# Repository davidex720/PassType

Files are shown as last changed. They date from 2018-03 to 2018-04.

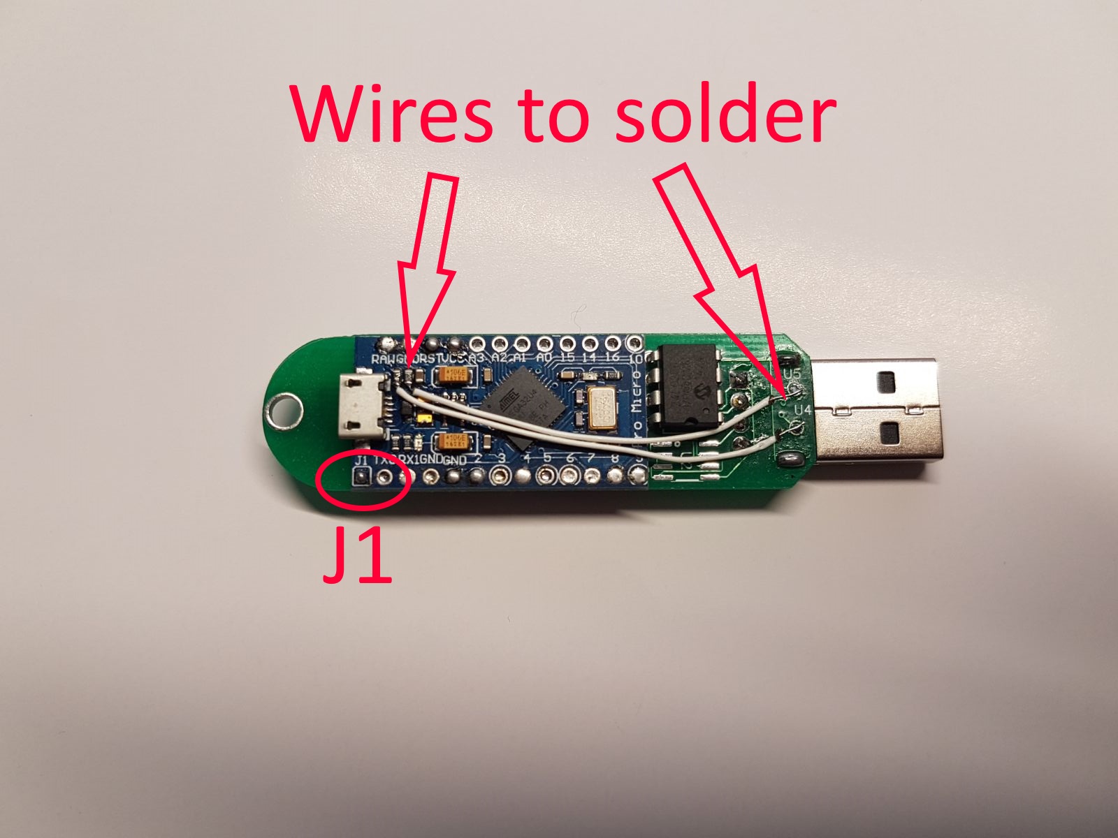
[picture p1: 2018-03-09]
PassType Shield/v1/Guide/backSide_PassTypeShield.jpg

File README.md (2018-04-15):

# PassType

#### A COMMERCIAL, UPGRADED AND "READY TO USE" VERSION IS COMING SOON!! READ MORE [HERE](https://github.com/davidex720/PassType/tree/master/PassType%20Pro)

PassType is small and versatile USB HID device: name something you can do with keyboard and mouse on your computer and PassType can do it for you faster, better and a million times over!

## The idea

Quite often you are requested to log in to accounts from a pc that is not yours, from a device you don't fully trust or to do repetitive tasks. You can use the always same password but it is a very bad practice with awfull consequences... you should use 10 characters or more passwords with numbers, symbols, upper and lower case letters in it and possibly change them once in a while. A nightmare to remember and even worse to type in right at first try. Sometimes one of my relatives have problems remembering a password, such as wifi or similar stuff. PassType (yeah... this name comes from the contraction of "password type in device") is a very cheap and simple to use automation device, capable of storing password and macros and to type/execute them in every device! It works with every computer and it can even be plugged and used on smartphones. Every system supporting some sort of keyboard and/or mouse is compatible with PassType!

## A versatile set of tools for newbies and pros

This small device can be used to perform tasks that are boring, repetitive or to type in hundreds of characters in few seconds. Actually it can do everything that a human in 15 minutes can do with mouse and keyboard in only few seconds. The first version of PassType is now called PassType Shield. The name comes from the fact that it is almost a shield for Arduino Pro Micro.
__The new version will be even more flexible, have a better storing system, encryption of datas and a lot of new features in a even smaller form factor!__

## Getting Started

You can build your own PassType from scratch, buy the pcb, the already smd soldered pcb or the full device from us directly.
Contact us at davidex720@gmail.com for pcbs and full devices. All files needed are in this repo (still to be updated)

__WEBSITE COMING SOON!__

## Authors

* **Davide Nesi** - *Dev*
* **Eero Prittinen** - *Dev*

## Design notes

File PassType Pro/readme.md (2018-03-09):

# COMING SOON!

## Feauters:

  - More power
  - Cool Design
  - Integrated safety measures to securely store passwords
  - Smaller size
  - Expandable memory
  - New learning tools
  - More compatibility
  - Professional tool easy to customize
  - Open to developer

www.passtype.it

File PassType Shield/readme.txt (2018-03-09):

PassType Shield is a prototype and it was first released as a project here:
http://www.instructables.com/id/Password-Manager-Typer-Macro-Payload-All-in-ONE/

It is a dirty and cheap prototype and still in evolution, 
it is a parallel work with the coming soon improved and boosted commercial version.

Go to www.passtype.it for more information about PassType

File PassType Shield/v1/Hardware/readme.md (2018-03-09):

# Parts list for PassType Shield V1
Links here are only for reference, feel free to buy parts from the cheapest alternative in your country.
This list is made for GLOBAL shipping

#### 1. PassType Shield PCB  
   - 5$ sending an email to davidex720@gmail.com 
   - the funds rised with PassType Shield pcb will be used for the development of the upgraded, safer, commercial, "ready to use" version of this project
   - Soon on www.passtype.it

#### 2. Arduino Pro Micro 5V
   - [Source 1](https://www.aliexpress.com/item/Free-Shipping-New-Pro-Micro-for-arduino-ATmega32U4-5V-16MHz-Module-with-2-row-pin-header/2021979132.html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,searchweb201602_1_10152_10151_10065_10344_10068_10342_10325_10343_10546_10340_10548_10341_10084_10083_10618_10304_10307_5711211_10313_10059_10184_10534_100031_10103_10627_10626_10624_10623_10622_5722411_10621_10620_5711311,searchweb201603_25,ppcSwitch_3&algo_expid=4f3b485b-808f-46f2-a339-12398b33a269-0&algo_pvid=4f3b485b-808f-46f2-a339-12398b33a269&priceBeautifyAB=0)
   - [Source 2](https://www.aliexpress.com/item/1pcs-TENSTAR-ROBOT-With-the-bootloader-Black-Pro-Micro-ATmega32U4-for-arduino-5V-16MHz-Module-controller/32849563958.html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,searchweb201602_1_10152_10151_10065_10344_10068_10342_10325_10343_10546_10340_10548_10341_10084_10083_10618_10304_10307_5711211_10313_10059_10184_10534_100031_10103_10627_10626_10624_10623_10622_5722411_10621_10620_5711311,searchweb201603_25,ppcSwitch_3&algo_expid=4f3b485b-808f-46f2-a339-12398b33a269-2&algo_pvid=4f3b485b-808f-46f2-a339-12398b33a269&priceBeautifyAB=0)

#### 3. LED (128x32) (you can choose letter color: blue or white usually)
   - [Source 1](https://it.aliexpress.com/item/1pcs-0-91-inch-OLED-module-0-91-white-OLED-128X32-OLED-LCD-LED-Display-Module/32672327708.html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,searchweb201602_1_10152_10151_10065_10344_10068_10342_10325_10343_10546_10340_10548_10341_10084_10083_10618_10304_10307_5711211_10313_10059_10184_10534_100031_10103_10627_10626_10624_10623_10622_5722411_10621_10620_5711311,searchweb201603_25,ppcSwitch_3&algo_expid=b9f97773-6c42-4b48-bd19-fa79ab7d9f12-1&algo_pvid=b9f97773-6c42-4b48-bd19-fa79ab7d9f12&priceBeautifyAB=0)
   - [Source 2](https://www.aliexpress.com/item/A3-1pcs-SAMIORE-ROBOT-0-91-inch-OLED-module-0-91-white-OLED-128X32-OLED-LCD/32672229793.html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,searchweb201602_1_10152_10151_10065_10344_10068_10342_10325_10343_10546_10340_10548_10341_10084_10083_10618_10304_10307_5711211_10313_10059_10184_10534_100031_10103_10627_10626_10624_10623_10622_5722411_10621_10620_5711311,searchweb201603_25,ppcSwitch_3&algo_expid=35dfc6a5-9fdb-4644-8a68-d7f9d38b9d17-1&algo_pvid=35dfc6a5-9fdb-4644-8a68-d7f9d38b9d17&priceBeautifyAB=0)

#### 4. 5-way tactile switch
   - [Source 1](https://www.aliexpress.com/item/5-Channel-Way-Tactile-Switch-Breakout-Module-Converter-Adapter-Board-for-Arduino/32669811425.html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,searchweb201602_1_10152_10151_10065_10344_10068_10342_10325_10343_10546_10340_10548_10341_10084_10083_10618_10304_10307_5711211_10313_10059_10184_10534_100031_10103_10627_10626_10624_10623_10622_5722411_10621_10620_5711311,searchweb201603_25,ppcSwitch_3&algo_expid=3273e035-9a04-4fd0-adfe-733925e676be-0&algo_pvid=3273e035-9a04-4fd0-adfe-733925e676be&priceBeautifyAB=0)  (to desolder) 
   - [Source 2](https://www.aliexpress.com/item/free-shipping-10-pcs-7mm-x-7mm-6-Pin-5-Way-Momentary-Pushbutton-PCB-SMD-SMT/32416530444.html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,searchweb201602_1_10152_10151_10065_10344_10068_10342_10325_10343_10546_10340_10548_10341_10084_10083_10618_10304_10307_5711211_10313_10059_10184_10534_100031_10103_10627_10626_10624_10623_10622_5722411_10621_10620_5711311,searchweb201603_25,ppcSwitch_3&algo_expid=3273e035-9a04-4fd0-adfe-733925e676be-2&algo_pvid=3273e035-9a04-4fd0-adfe-733925e676be&priceBeautifyAB=0)

#### 5. EEPROM 24lc256
   - Best solution is to ask for free samples and free shipping [here](http://www.microchip.com/wwwproducts/en/24lc256)
   - Or you can buy it [here](https://www.digikey.com/product-detail/en/microchip-technology/24LC256T-I-SM/24LC256T-I-SMCT-ND/5013518)

#### 6. USB male connector
   - [Source 1](https://www.aliexpress.com/item/50Pcs-lot-USB-2-0-Male-A-Type-USB-PCB-Connector-Plug-180-degree-SMT-SMD/32707919597.html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,searchweb201602_1_10152_10151_10065_10344_10068_10342_10325_10343_10546_10340_10548_10341_10084_10083_10618_10304_10307_5711211_10313_10059_10184_10534_100031_10103_10627_10626_10624_10623_10622_5722411_10621_10620_5711311,searchweb201603_25,ppcSwitch_3&algo_expid=a10d68d0-b656-4def-88e3-eda41a465fa2-3&algo_pvid=a10d68d0-b656-4def-88e3-eda41a465fa2&priceBeautifyAB=0)
   - [Source 2](https://www.aliexpress.com/item/82Pcs-14-Styles-USB-Male-USB-Female-Mini-USB-SMD-Vertical-Socket-Connector-for-DIY-Jack/32821827485.html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,searchweb201602_1_10152_10151_10065_10344_10068_10342_10325_10343_10546_10340_10548_10341_10084_10083_10618_10304_10307_5711211_10313_10059_10184_10534_100031_10103_10627_10626_10624_10623_10622_5722411_10621_10620_5711311,searchweb201603_25,ppcSwitch_3&algo_expid=a10d68d0-b656-4def-88e3-eda41a465fa2-8&algo_pvid=a10d68d0-b656-4def-88e3-eda41a465fa2&priceBeautifyAB=0)

## YOU DO NOT NEED SPARE RESISTORS FOR THIS VERSION OF PASSTYPE SHIELD!!!

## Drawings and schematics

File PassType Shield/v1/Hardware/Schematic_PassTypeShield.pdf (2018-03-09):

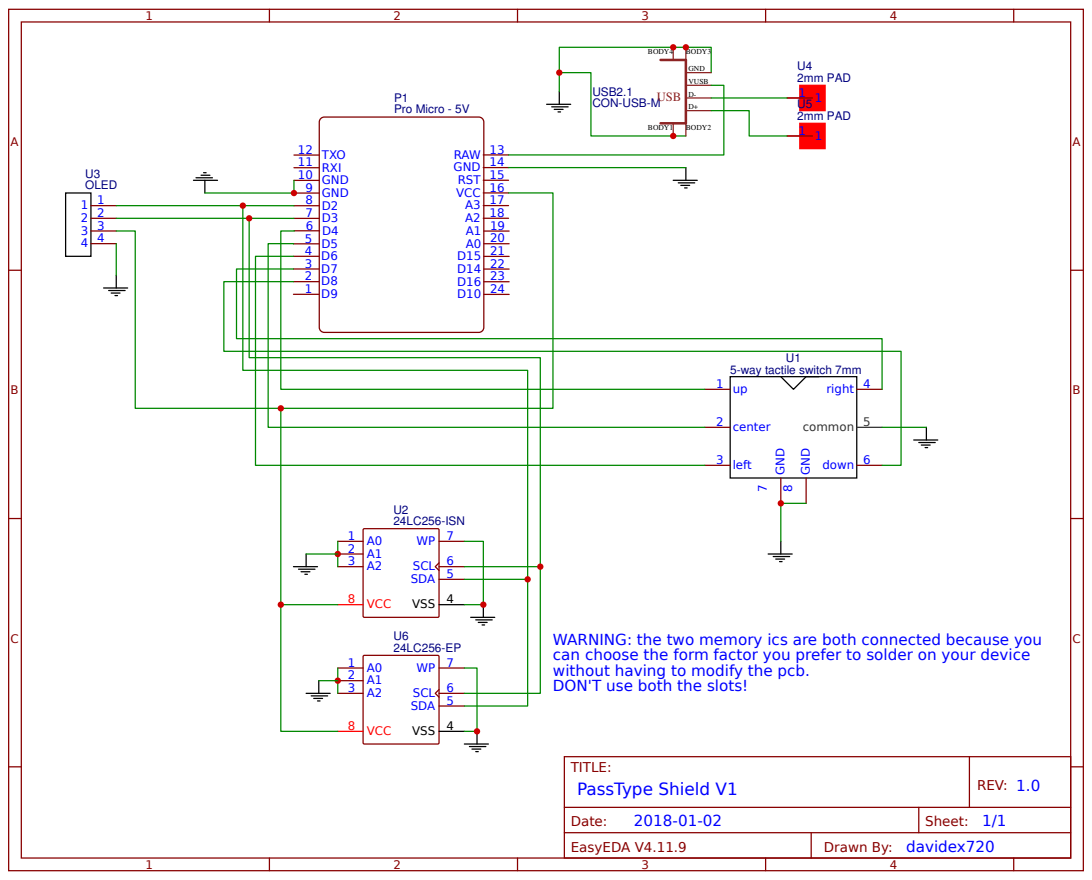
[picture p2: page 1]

WARNING: the two memory ics are both connected because you
can choose the form factor you prefer to solder on your device
without having to modify the pcb.
DON'T use both the slots!

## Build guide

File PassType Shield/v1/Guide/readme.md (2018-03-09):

#Step by step guide building DIY PassType Shield

1. Solder the 24LC256 to the PassType Shield pcb. Choose only one of the two sockets (smd or arduino pin compatible package)

2. Solder the USB male connector if you have a PassType Shield pcb without it already soldered on it

3. Solder the OLED module in position and trim away the pins

4. Solder the Arduino Pro Micro as flush as you can with the pcb using pins and trim them
  4.1 If you have an Arduino Pro Micro with J1 open solder the jumper close (see image) 

5. Solder two small wires as in the picture, they will provide data output to the USB connector integrated on PassType Shield 
**BE SUPER CAREFUL ABOUT THE SOLDERING ON ARDUINO PRO MICRO! IF YOU HEAT TOO MUCH THE BOARD OR MAKE THE WRONG SOLDERING YOU CAN DAMAG YOUR ARDUINO!**

6. Solder the 5-way switch (the mini joystick)

7. Plug the Arduino Pro Micro micro usb port on your computer and check you can programm it. Now feel free to develop your software
   use the one you find in this github repo! 

8. Enjoy!

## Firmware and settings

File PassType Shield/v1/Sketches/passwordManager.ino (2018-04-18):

//TODO add more settings
//TODO login/unlock
//TODO psw names with upper and lower case
//TODO accept only showrt password names
//TODO optimize memory
//TODO graphic revision for arrows
//TODO long press = multiple press
//TODO add more chars
//TODO standby function
//TODO get a better randPSW
//TODO RESET SYSTEM AFTER 3 WRONG LOGIN ATTEMPTS
//TODO add scrolling text for long names





#include <U8g2lib.h>
#include <Wire.h>
#include "Keyboard.h"


//DISPLAY CONSTRUCTOR
U8G2_SSD1306_128X32_UNIVISION_F_HW_I2C u8g2(U8G2_R0, SCL, SDA, U8X8_PIN_NONE);
//U8G2_SSD1306_128X32_UNIVISION_F_HW_I2C u8g2(U8G2_R2, SCL, SDA, U8X8_PIN_NONE);



//EEPROM VALUE
#define disk1 0x50
#define byteResetValue 255
#define endAddressZone 255
#define dimPSW 40
#define startPSWzone 5000
#define endPSWzone 15200
#define settingStartAddress 32500

//Settings
#define firstUse 32501              //255 first use
#define pswLength 32502             //5,6,7,8,9,10,11,12,13,14,15,16  ---------default 10 value 255
#define pswType  32503              //1 only lowercase, 2 lower+upper case, 3 letters+numbers, 4 letters+numbers+symbols -------255 default letters+numbers

//JOYSTICK
#define upPin  4
#define centerPin  5
#define leftPin  6
#define rightPin  7
#define downPin  8

//setting per UI
#define longPressedTime 40
#define longPressQuant  7


#define spacing 12   //spacing
#define pswLength 10

int buttonState;
int lastButtonState = 0;
int cyclePressed = 0;



//BITMAPS
const u8g2_uint_t leftArrow[]  = {
  0x00,          // 00000000
  0x20,          // 00100000
  0x60,          // 01100000
  0xE0,          // 11100000
  0xE0,          // 11100000
  0x60,          // 01100000
  0x20,          // 00100000
  0x00,          // 00000000
};
const u8g2_uint_t rigthArrow[]  = {
  0x00,          // 00000000
  0x80,          // 10000000
  0xC0,          // 11000000
  0xE0,          // 11100000
  0xE0,          // 11100000
  0xC0,          // 11000000
  0x80,          // 10000000
  0x00,          // 00000000
};
const u8g2_uint_t downArrow[]  = {
  0x00,          // 00000000
  //0x7E,          // 01111110
  0x3C,          // 00111100
  0x18,          // 00011000
};
const u8g2_uint_t upArrow[]  = {
  0x18,          // 00011000
  0x3C,          // 00111100
  //0x7E,          // 01111110
  0x00,          // 00000000
};

const u8g2_uint_t center[]  = {
  0x3C,          // 00111100
  0x42,          // 01000010
  0x5A,          // 01011010
  0x5A,          // 01011010
  0x42,          // 01000010
  0x3C,          // 00111100
};

const u8g2_uint_t verticalTYPE[]  = { //TODO could use only letters ad mitmaps to optimize memory
  0x70,          // 01110000
  0x20,          // 00100000
  0x20,          // 00100000
  0x20,          // 00100000
  0x20,          // 00100000
  0x00,          // 00000000

  0x50,          // 01010000
  0x50,          // 01010000
  0x20,          // 00100000
  0x20,          // 00100000
  0x20,          // 00100000
  0x00,          // 00000000

  0x70,          // 01110000
  0x50,          // 01010000
  0x70,          // 01110000
  0x40,          // 01000000
  0x40,          // 01000000
  0x00,          // 00000000

  0x70,          // 01110000
  0x40,          // 01000000
  0x70,          // 01110000
  0x40,          // 01000000
  0x70,          // 01110000
  0x00,          // 00000000

};

const u8g2_uint_t verticalEDIT[]  = {
  0x70,          // 01110000
  0x40,          // 01000000
  0x70,          // 01110000
  0x40,          // 01000000
  0x70,          // 01110000
  0x00,          // 00000000

  0x60,          // 01100000
  0x50,          // 01010000
  0x50,          // 01010000
  0x50,          // 01010000
  0x60,          // 01100000
  0x00,          // 00000000

  0x20,          // 00100000
  0x20,          // 00100000
  0x20,          // 00100000
  0x20,          // 00100000
  0x20,          // 00100000
  0x00,          // 00000000

  0x70,          // 01110000
  0x20,          // 00100000
  0x20,          // 00100000
  0x20,          // 00100000
  0x20,          // 00100000
  0x00,          // 00000000

};

const u8g2_uint_t verticalBACK[]  = {
  0x70,          // 01110000
  0x48,          // 01001000
  0x70,          // 01110000
  0x48,          // 01001000
  0x70,          // 01110000
  0x00,          // 00000000

  0x20,          // 00100000
  0x50,          // 01010000
  0x70,          // 01110000
  0x50,          // 01010000
  0x50,          // 01010000
  0x00,          // 00000000

  0x30,          // 00110000
  0x40,          // 01000000
  0x40,          // 01000000
  0x40,          // 01000000
  0x30,          // 00110000
  0x00,          // 00000000

  0x40,          // 01000000
  0x50,          // 01010000
  0x60,          // 01100000
  0x50,          // 01010000
  0x48,          // 01001000
  0x00,          // 00000000

};

const u8g2_uint_t verticalOK[]  = {
  0x20,          // 00100000
  0x50,          // 01010000
  0x50,          // 01010000
  0x50,          // 01010000
  0x20,          // 00100000
  0x00,          // 00000000

  0x40,          // 01000000
  0x50,          // 01010000
  0x60,          // 01100000
  0x50,          // 01010000
  0x48,          // 01001000
  0x00,          // 00000000

};

const uint8_t logo[] PROGMEM  = {
  0x00, 0x00, 0x00, 0x00, 0x00, 0x00, 0x00, 0x00, 0x00, 0x00, 0x00, 0x00, 0x00, 0x00, 0x00, 0x00
  , 0x00, 0x00, 0x00, 0x00, 0x00, 0x00, 0x00, 0x00, 0x00, 0x00, 0x00, 0x00, 0xfe, 0xff, 0x03, 0x00
  , 0x00, 0x00, 0x00, 0x00, 0x00, 0x00, 0x00, 0x00, 0x00, 0x00, 0x00, 0x00, 0xff, 0xff, 0x07, 0x00
  , 0x00, 0x00, 0x00, 0x00, 0x00, 0x00, 0x00, 0x00, 0x00, 0x00, 0x00, 0x80, 0x03, 0x00, 0x0e, 0x00
  , 0x00, 0x00, 0x00, 0x00, 0x00, 0x00, 0x00, 0x00, 0x00, 0x00, 0x00, 0xc0, 0x01, 0x00, 0x1c, 0x00
  , 0x00, 0x00, 0x00, 0x00, 0x00, 0x00, 0x00, 0x00, 0x00, 0x00, 0x1c, 0xe0, 0x00, 0x00, 0x38, 0x00
  , 0x00, 0x00, 0x00, 0x00, 0x00, 0x00, 0x00, 0x00, 0x00, 0x00, 0x7e, 0x70, 0x00, 0x00, 0x70, 0x00
  , 0x00, 0x00, 0x00, 0x00, 0x00, 0x00, 0x00, 0x00, 0x00, 0x00, 0xfe, 0x3f, 0x00, 0x00, 0xe0, 0x00
  , 0x00, 0x00, 0xc0, 0x07, 0x00, 0x00, 0x00, 0x03, 0x00, 0x00, 0xfe, 0x1f, 0x00, 0x00, 0xc0, 0x00
  , 0x00, 0x00, 0xe0, 0x1f, 0x00, 0x00, 0x0e, 0x03, 0x00, 0x7e, 0xfe, 0x1f, 0x00, 0x00, 0xc0, 0x00
  , 0x00, 0x00, 0x64, 0x38, 0x00, 0x83, 0x0f, 0x07, 0x00, 0xff, 0x00, 0x1c, 0x00, 0x00, 0xc0, 0x00
  , 0x00, 0x00, 0x66, 0x30, 0x80, 0xc7, 0x03, 0xbf, 0x40, 0xc3, 0x7c, 0x1c, 0x00, 0xf8, 0xc0, 0x00
  , 0x00, 0x00, 0xe7, 0x9f, 0xc1, 0x6c, 0x00, 0xbf, 0x61, 0xc3, 0xfe, 0x1c, 0x00, 0x04, 0xc1, 0x00
  , 0x00, 0x80, 0xe7, 0x8f, 0x67, 0x60, 0x00, 0x83, 0x61, 0x7f, 0xc6, 0x1c, 0x00, 0x02, 0xc2, 0x00
  , 0x00, 0xc0, 0xe3, 0x00, 0x6f, 0xc0, 0x07, 0x83, 0x63, 0x3f, 0xc6, 0x1c, 0x00, 0x02, 0xc2, 0x00
  , 0x00, 0xe0, 0xe3, 0x00, 0xcc, 0x87, 0x0f, 0x03, 0x7f, 0x03, 0xfe, 0x1c, 0x00, 0x02, 0xc2, 0x00
  , 0x00, 0xe0, 0xe3, 0x00, 0x8c, 0x0f, 0x0c, 0x03, 0x7e, 0x03, 0x7e, 0x1c, 0x00, 0x02, 0xc2, 0x00
  , 0x00, 0xe0, 0xe3, 0xc0, 0x0f, 0x0c, 0x0c, 0x03, 0x60, 0x03, 0x06, 0x1c, 0x00, 0x02, 0xc2, 0x00
  , 0x00, 0xc0, 0xe3, 0x60, 0x0c, 0x0e, 0x0f, 0x07, 0x70, 0x03, 0x06, 0x1c, 0x00, 0x04, 0xc1, 0x00
  , 0x00, 0x80, 0xe7, 0x60, 0xec, 0xe7, 0x07, 0xbe, 0x3f, 0x03, 0x7c, 0x1c, 0x00, 0xf8, 0xc0, 0x00
  , 0x00, 0x00, 0xe7, 0xc0, 0xef, 0xe3, 0x01, 0xbc, 0x1f, 0x03, 0x7c, 0x1c, 0x00, 0x00, 0xc0, 0x00
  , 0x00, 0x00, 0x06, 0x00, 0x00, 0x00, 0x00, 0x00, 0x00, 0x00, 0x00, 0x1c, 0x00, 0x00, 0xc0, 0x00
  , 0x00, 0x00, 0xfc, 0xff, 0xff, 0xff, 0xff, 0xff, 0xff, 0xff, 0xff, 0x1f, 0x00, 0x00, 0xc0, 0x00
  , 0x00, 0x00, 0xf8, 0xff, 0xff, 0xff, 0xff, 0xff, 0xff, 0xff, 0xff, 0x3f, 0x00, 0x00, 0xe0, 0x00
  , 0x00, 0x00, 0x00, 0x00, 0x00, 0x00, 0x00, 0x00, 0x00, 0x00, 0x00, 0x70, 0x00, 0x00, 0x70, 0x00
  , 0x00, 0x00, 0x00, 0x00, 0x00, 0x00, 0x00, 0x00, 0x00, 0x00, 0x00, 0xe0, 0x00, 0x00, 0x38, 0x00
  , 0x00, 0x00, 0x00, 0x00, 0x00, 0x00, 0x00, 0x00, 0x00, 0x00, 0x00, 0xc0, 0x01, 0x00, 0x1c, 0x00
  , 0x00, 0x00, 0x00, 0x00, 0x00, 0x00, 0x00, 0x00, 0x00, 0x00, 0x00, 0x80, 0x03, 0x00, 0x0e, 0x00
  , 0x00, 0x00, 0x00, 0x00, 0x00, 0x00, 0x00, 0x00, 0x00, 0x00, 0x00, 0x00, 0xff, 0xff, 0x07, 0x00
  , 0x00, 0x00, 0x00, 0x00, 0x00, 0x00, 0x00, 0x00, 0x00, 0x00, 0x00, 0x00, 0xfe, 0xff, 0x03, 0x00
  , 0x00, 0x00, 0x00, 0x00, 0x00, 0x00, 0x00, 0x00, 0x00, 0x00, 0x00, 0x00, 0x00, 0x00, 0x00, 0x00
  , 0x00, 0x00, 0x00, 0x00, 0x00, 0x00, 0x00, 0x00, 0x00, 0x00, 0x00, 0x00, 0x00, 0x00, 0x00, 0x00

};




























String text = "no";
int pointedAddr = 0;
int statusMenu = 0;
String addName;
int charInName = 0;
int charIndex = 0;
int wait = 5;
int fUse = 255;


char consentiti[] = {
  ' '                                                                                                                                            //  1
  , 'a', 'b', 'c', 'd', 'e', 'f', 'g', 'h', 'i', 'j', 'k', 'l', 'm', 'n', 'o', 'p', 'q', 'r', 's', 't', 'u', 'v', 'w', 'x', 'y', 'z'             //+26
  , 'A', 'B', 'C', 'D', 'E', 'F', 'G', 'H', 'I', 'J', 'K', 'L', 'M', 'N', 'O', 'P', 'Q', 'R', 'S', 'T', 'U', 'V', 'W', 'X', 'Y', 'Z'             //+26
  , '0', '1', '2', '3', '4', '5', '6', '7', '8', '9'                                                                                             //+10 =63
  , '?', '(', ',', ')', '/', '&', '%', '$', '<', '>', '!', ']', '+', '_', '*', '.', '}', '@', '^',                                                //+19 =82
  // _     )   ,    =   -     /    %    $    ;    :    !    +    ^    ?    (    .    *    "    &


};



void setup(void) {

  pinMode(4, INPUT_PULLUP);
  pinMode(5, INPUT_PULLUP);
  pinMode(6, INPUT_PULLUP);
  pinMode(7, INPUT_PULLUP);
  pinMode(8, INPUT_PULLUP);

  u8g2.begin();
  u8g2.setFont(u8g2_font_crox4h_tr);

  Serial.begin(9600);
  Wire.begin();
  Keyboard.begin();
  randomSeed(analogRead(0));

  fUse = (int) readEEPROM(firstUse);
  if (fUse == 255) {
    //TODO first use
    //TODO set to firs use done
  } else {
    //animation
  }

}

void loop(void) {

  if (wait == 0) {
  } else if (wait == 5) {
    wait++;
  } else if (wait == 6) {
    delay(2000);
    wait = 0;
  } else {
    delay(1000);
    wait = 0;
  }

  String n;
  String v;

  if (statusMenu <= 1) {
    if (simpleAutoReadPSW(pointedAddr, &n, &v)) {
      text = n;
      statusMenu = 1;
    } else {
      text = "New PSW";
      statusMenu = 2;
    }
  }

  debounceButtons();

  //0 nothing
  //1 left
  //2 up
  //3 right
  //4 down
  //5 center
  //6 dont know

  if (statusMenu == 1) {          //------------------------------------show psw name
    if (buttonState == 0) {
      //nothing
    } else if (buttonState == 1) { //left
      //TODO typing animation
      Keyboard.print(v);
    } else if (buttonState == 2) { //up
      if (pointedAddr > 0) {
        pointedAddr--;
      }
    } else if (buttonState == 3) { //right
      text = "Edit name";
      statusMenu = 4;
    } else if (buttonState == 4) { //down
      if (pointedAddr < 250) {
        pointedAddr++;
      }
    } else if (buttonState == 5) { //center
      statusMenu = 2;
    } else if (buttonState == 6) { //boh
    }


  } else if (statusMenu == 2) {    //-------------------------------------new psw
    if (buttonState == 0) {
      //nothing
    } else if (buttonState == 2) { //up
      int tm = 0;
      if (pointedAddr > 0) {
        tm = pointedAddr - 1;
      }
      if (simpleAutoReadPSW(tm, &n, &v)) {
        text = n;
        statusMenu = 1;
        pointedAddr--;
      } else {
        text = "New PSW";
        statusMenu = 2;
      }
    } else if (buttonState == 3) { //right
      text = "Insert name";
      statusMenu = 7;
    } else if (buttonState == 4) { //down
      text = "Settings";
      statusMenu = 3;
    } else if (buttonState == 5) { //center
      statusMenu = 1;
      pointedAddr = 0;
    } else if (buttonState == 6) { //boh
    }



  } else if (statusMenu == 3) {    //----------------------------------------- settings
    if (buttonState == 0) {
      //nothing
    } else if (buttonState == 2) { //up
      text = "New PSW";
      statusMenu = 2;
    } else if (buttonState == 3) { //right
      statusMenu = 10;
      text = "Psw length";
    } else if (buttonState == 4) { //down
    } else if (buttonState == 5) { //center
    } else if (buttonState == 6) { //boh
    }



  } else if (statusMenu == 4) {    //-----------------------------------------"edit name"
    if (buttonState == 0) {
      //nothing
    } else if (buttonState == 1) { //left
      statusMenu = 1;
    } else if (buttonState == 2) { //up
    } else if (buttonState == 3) { //right
      simpleAutoReadPSW(pointedAddr, &n, &v);
      addName = n;
      charInName = n.length();
      charIndex = 0;
      statusMenu = 9;
    } else if (buttonState == 4) { //down
      text = "Edit Val";
      statusMenu = 5;
    } else if (buttonState == 5) { //center
    } else if (buttonState == 6) { //boh
    }



  } else if (statusMenu == 5) {    //-----------------------------------------"edit val"
    if (buttonState == 0) {
      //nothing
    } else if (buttonState == 1) { //left
      statusMenu = 1;
    } else if (buttonState == 2) { //up
      text = "Edit name";
      statusMenu = 4;
    } else if (buttonState == 3) { //right
      //TODO editing
      recreatePSW(pointedAddr);
      statusMenu = 1;
      wait = 4;
    } else if (buttonState == 4) { //down
      text = "Delete PSW";
      statusMenu = 6;
    } else if (buttonState == 5) { //center
    } else if (buttonState == 6) { //boh
    }



  } else if (statusMenu == 6) {    //----------------------------------------- "delete psw"
    if (buttonState == 0) {
      //nothing
    } else if (buttonState == 1) { //left
      statusMenu = 1;
    } else if (buttonState == 2) { //up
      text = "Edit val";
      statusMenu = 5;
    } else if (buttonState == 3) { //right
      deletePSW(pointedAddr);
      if (pointedAddr != 0) {
        pointedAddr--;
      }
      statusMenu = 1;
      wait = 3;
      //TODO schermata di conferma
    } else if (buttonState == 4) { //down
    } else if (buttonState == 5) { //center
    } else if (buttonState == 6) { //boh
    }



  } else if (statusMenu == 7) {    //----------------------------------------------"insert name"
    if (buttonState == 0) {
      //nothing
    } else if (buttonState == 1) { //left
      text = "New PSW";
      statusMenu = 2;
    } else if (buttonState == 2) { //up
    } else if (buttonState == 3) { //right
      //TODO insert value
      statusMenu = 8;
    } else if (buttonState == 4) { //down
    } else if (buttonState == 5) { //center
    } else if (buttonState == 6) { //boh
    }



  } else if (statusMenu == 8) {    //---------------------------------------------- inserting the name
    if (buttonState == 0) {
      //nothing
    } else if (buttonState == 1) { //left
      if (charInName == 0) {
        //TODO return back
        text = "Insert name";
        statusMenu = 7;
      } else {
        addName.remove(addName.length() - 1);
        charInName--;
        charIndex = 0;
      }
    } else if (buttonState == 2) { //up
      charIndex++;
      if (charIndex >= 27) {
        charIndex = 0;
      }
    } else if (buttonState == 3) { //right
      if (charIndex == 0) {
        if (charInName != 0) {
          autoWritePSW(addName , rndPSWgen());
          //TODO messaggio
          charIndex = 0;
          charInName = 0;
          addName = "";
          pointedAddr--;
          statusMenu = 0;
          wait = 2;
        } else {
          //TODO nto valid name
        }
      } else {
        addName = addName + consentiti[charIndex];
        charIndex = 0;
        charInName++;
      }
    } else if (buttonState == 4) { //down
      charIndex--;
      if (charIndex < 0) {
        charIndex = 26;
      }
    } else if (buttonState == 5) { //center
    } else if (buttonState == 6) { //boh
    }



  } else if (statusMenu == 9) {    //---------------------------------------------- editing the name
    if (buttonState == 0) {
      //nothing
    } else if (buttonState == 1) { //left
      if (charInName == 0) {
        //TODO return back
        text = "Edit name";
        statusMenu = 4;
      } else {
        addName.remove(addName.length() - 1);
        charInName--;
        charIndex = 0;
      }
    } else if (buttonState == 2) { //up
      charIndex++;
      if (charIndex >= 27) {
        charIndex = 0;
      }
    } else if (buttonState == 3) { //right
      if (charIndex == 0) {
        if (charInName != 0) {
          //TODO change name
          //n;
          //v;
          //pointedAddr;
          simpleAutoReadPSW(pointedAddr, &n, &v);
          int indx = (int) readEEPROM(pointedAddr);
          int eeaddress = startPSWzone + (dimPSW * indx);
          resetEEPROM(eeaddress, eeaddress + dimPSW - 1);
          writeEEPROM(eeaddress, 1);
          for (int i = 0; i < addName.length(); i++) {
            writeEEPROM(eeaddress + 1 + i, addName.charAt(i));
          }
          int tmp = eeaddress + 1 + addName.length();
          writeEEPROM(tmp, 2);
          for (int k = 0; k < v.length(); k++) {
            writeEEPROM(tmp + 1 + k, v.charAt(k));
          }
          writeEEPROM(tmp + 1 + v.length(), 3);
          //TODO message
          charIndex = 0;
          charInName = 0;
          addName = "";
          statusMenu = 0;
          wait = 1;
        } else {
          //TODO not valid message
        }
      } else {
        addName = addName + consentiti[charIndex];
        charIndex = 0;
        charInName++;
      }
    } else if (buttonState == 4) { //down
      charIndex--;
      if (charIndex < 0) {
        charIndex = 26;
      }
    } else if (buttonState == 5) { //center
    } else if (buttonState == 6) { //boh
    }



  } else if (statusMenu == 10) {                                           // setting "psw length"
    if (buttonState == 0) {
      //nothing
    } else if (buttonState == 1) { //left
      text = "Settings";
      statusMenu = 3;
    } else if (buttonState == 2) { //up
    } else if (buttonState == 3) { //right
      statusMenu = 12;
      charIndex = (int) readEEPROM(pswLength);
      if (charIndex == 255) {
        charIndex = 10;
        writeEEPROM(pswLength, 10);
      }
    } else if (buttonState == 4) { //down
      statusMenu = 11;
      text = "Psw type";
    } else if (buttonState == 5) { //center
    } else if (buttonState == 6) { //boh
    }



  } else if (statusMenu == 11) {                                           // setting "psw type"
    if (buttonState == 0) {
      //nothing
    } else if (buttonState == 1) { //left
      text = "Settings";
      statusMenu = 3;
    } else if (buttonState == 2) { //up
      statusMenu = 10;
      text = "Psw length";
    } else if (buttonState == 3) { //right
      statusMenu = 13;
      text = "alphabetic";
    } else if (buttonState == 4) { //down
      statusMenu = 17;
      text = "Erase all";
    } else if (buttonState == 5) { //center
    } else if (buttonState == 6) { //boh
    }


  } else if (statusMenu == 17) {                                           // setting erase all
    if (buttonState == 0) {
      //nothing
    } else if (buttonState == 1) { //left
      text = "Settings";
      statusMenu = 3;
    } else if (buttonState == 2) { //up
      statusMenu = 11;
      text = "Psw type";
    } else if (buttonState == 3) { //right
      statusMenu = 18;
      text = "Sure?";
    } else if (buttonState == 4) { //down
    } else if (buttonState == 5) { //center
    } else if (buttonState == 6) { //boh
    }


  } else if (statusMenu == 18) {                                           // "sure?"
    if (buttonState == 0) {
      //nothing
    } else if (buttonState == 1) { //left
      text = "Settings";
      statusMenu = 3;
    } else if (buttonState == 2) { //up
    } else if (buttonState == 3) { //right
      resetEEPROM(0, 7000);
      statusMenu = 0;
      wait = 7;
    } else if (buttonState == 4) { //down
    } else if (buttonState == 5) { //center
    } else if (buttonState == 6) { //boh
    }



  } else if (statusMenu == 12) {    //---------------------------------------------- editing the PSW length
    if (buttonState == 0) {
      //nothing
    } else if (buttonState == 1) { //left
      statusMenu = 10;
      text = "Psw length";
    } else if (buttonState == 2) { //up
      charIndex++;
      if (charIndex >= 17) {
        charIndex = 6;
      }
    } else if (buttonState == 3) { //right
      int t = (int) readEEPROM(pswLength);
      if (charIndex != t) {
        writeEEPROM(pswLength, charIndex);
      }
      charIndex = 0;
      statusMenu = 10;
      text = "Psw length";
      wait = 1;
    } else if (buttonState == 4) { //down
      charIndex--;
      if (charIndex < 6) {
        charIndex = 16;
      }
    } else if (buttonState == 5) { //center
    } else if (buttonState == 6) { //boh
    }



  } else if (statusMenu == 13) {                                           //psw alphabetic
    if (buttonState == 0) {
      //nothing
    } else if (buttonState == 1) { //left
      statusMenu = 11;
      text = "Psw type";
    } else if (buttonState == 2) { //up
    } else if (buttonState == 3) { //right
      int val = (int) readEEPROM(pswType);
      if (val == 255 || val != 1) {
        writeEEPROM(pswType, 1);
      }
      statusMenu = 11;
      text = "Psw type";
      wait = 1;
    } else if (buttonState == 4) { //down
      statusMenu = 14;
      text = "AlphaBetic";
    } else if (buttonState == 5) { //center
    } else if (buttonState == 6) { //boh
    }
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
